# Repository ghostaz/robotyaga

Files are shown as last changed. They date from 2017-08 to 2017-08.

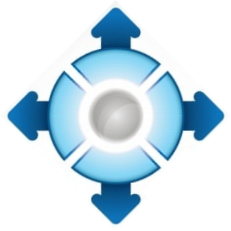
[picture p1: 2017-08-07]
Приложение/image/Стрелки.png

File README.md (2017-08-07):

# Роботяга
Платформа для сборки робота своими руками.
Вся информация по проекту доступна на сайте http://роботяга.рф

Коротко о платформе "Роботяга".
Платформа представляет собой гусеничное шасси с электронной платой. На плате содержится драйвер двигателя, аккумуляторы и микроконтроллер управляющий двигателями.
Взаимодействие с платформой осуществялется по проводному или беспроводному (Bluetooth) каналу через API. API позволяет управлять мощностью двигателей, получать заряд аккуумулятора. В дальнейшем планируется дополнить API и прошивку функционалом одометрии и работы платформы как ноды ROS.

Платформа предоставляет не только функции движения робота, но и функции питания. Втроенный аккумулятор имет защиту от перезаряда, переразряда, балансировку. На корпусы выведены 12 вольт непосредственно с аккумулыторов, 5 вольт через понижающий преобразователь с сильй тока до 2 ампер. Это позволяет вам подключить свое оборудование. Например, Raspberry Pi.

В даннмо репозитории выкладываются исходники схем. Использование схем бесплатно, исходники открыты по лицензией GPL v3. Прошивка микроконтроллера распрастраняется так же бесплатно, но исходники не предоставляются.

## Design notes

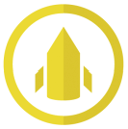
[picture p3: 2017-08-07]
Приложение/image/appico_hdpi.png

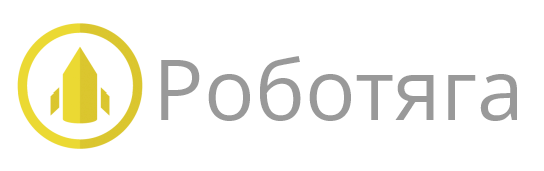
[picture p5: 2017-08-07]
Приложение/image/ЛогоМал.png

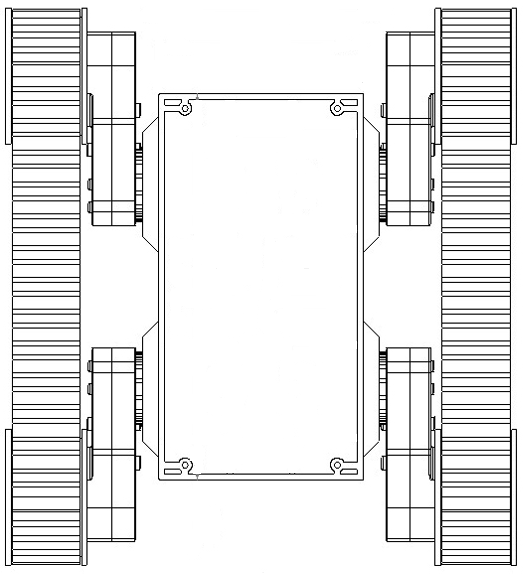
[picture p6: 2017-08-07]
Приложение/image/ВидСверху.png

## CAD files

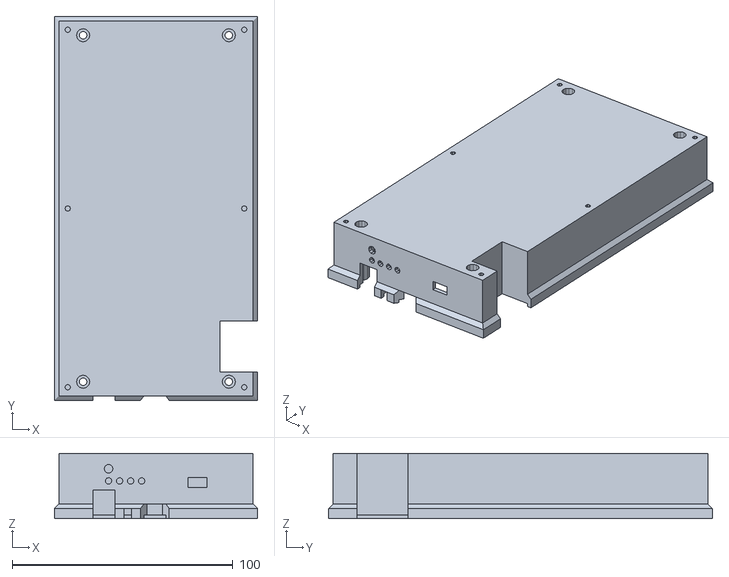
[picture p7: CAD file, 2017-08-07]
Корпус/Корпус_v1.4.stl
92.0 x 174.0 x 29.6

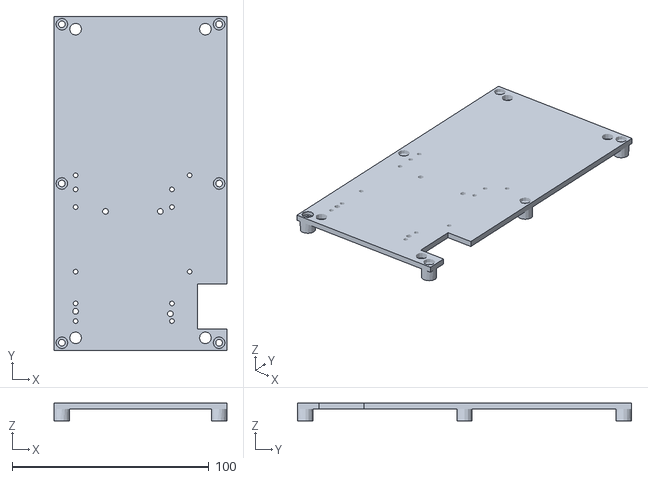
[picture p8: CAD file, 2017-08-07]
Корпус/Корпус_v1.4_Верх.stl
88.0 x 170.0 x 9.00

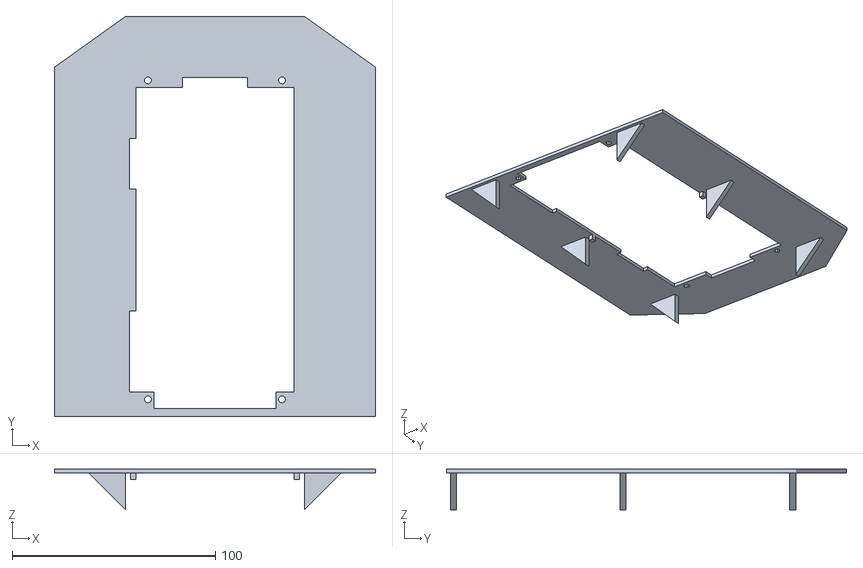
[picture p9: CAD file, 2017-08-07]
Корпус/Корпус_v1.4_Крыло.stl
158.0 x 197.0 x 20.0

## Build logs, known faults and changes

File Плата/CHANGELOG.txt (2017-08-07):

Версия 1.3 - Начата 26.03.2017
1 - Увеличено посадочное место под резистор 330Ом
2 - Разъем для индикатора заряда перенесен к выключаетлю
3 - Разъем питания Monster Shield изменени на разьем с 2мя контактами с шагом 2.54
4 - Разьемы питания на плате составлены таким образом что бы все провода были стандартными и подходили для любого разъема
5 - Отверстия для проброски проводов в корпус сделаны открытыми
6 - Знаки + и - для коннекторов моторов смещены, так что бы были видны после пайки коннектора
7 - Знаки + и - для держателя батарей смещены наружу, т.к. закрывались держателем
8 - Отверстия для крпления платы увеличены и перенесены на 0,5мм
9 - Увеличены отверстия для разъема DC3016
10 - Обозначения контактов выведен за границы, иначе были не видны
11 - Плата заряда батареи сдвинут внутрь корпуса
12 - Сдвинуты на пол миллиметра выключатель и разем питания что бы немешать корпусу.

Версия 1.4 - Начата 15.05.2017
1 - Добавлен регулятор напряжения на 5 вольт для питания Raspberry Pi
2 - Надпись Роботяга сделана на киррилице.

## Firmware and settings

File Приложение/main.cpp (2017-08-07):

#include <QGuiApplication>
#include <QQmlApplicationEngine>
#include <QQmlContext>
#include <QtQuick/QQuickView>

#include "bluetoothmanager.h"


int main(int argc, char *argv[])
{

    QCoreApplication::setAttribute(Qt::AA_EnableHighDpiScaling);
    QGuiApplication app(argc, argv);
    QQuickView view;

    BluetoothManager bluetoothManager;
    view.rootContext()->setContextProperty("bluetoothManager", QVariant::fromValue(&bluetoothManager));

    view.setSource(QUrl(QStringLiteral("qrc:/main.qml")));
    view.setResizeMode(QQuickView::SizeRootObjectToView);

    view.show();
    return app.exec();

}

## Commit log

2017-03-01 Добавил файл схемы платы
2017-03-03 Добавил открытую лицензию для проекта
2017-03-05 Добавил прошивку
2017-03-13 Добавил прошивку версии 0.1.0.13
2017-06-19 Rename Корпус_v1.3 - Верх.stl to Корпус_v1.3_Верх.stl
    [Корпус_v1.3_Верх.stl]
2017-07-22 Add files via upload
    Версия 1.5 - Начата 13.06.2017
    1 - Исправлено критически близкое положение минуса батареи и плюса модуля Bluetooth
2017-07-22 Версия 1.4 - Начата 21.07.2017 - Мелкие доработки
    Корпус - Версия 1.4 - Начата 21.07.2017
    1 - Крыло удленнено на 2 мм. Иначе ее размер ограничивался размером Rover5, а корпус сверху выстулпа на 2 мм
    2 - Модернизировано крпление датчика уровня заряда. Теперь установка проще.
    3 - Вырез под выключатель сделан шыре для удобства.
    4 - В крыле сделан вырез под контакты. Без выреза плата не устанавливается.
    6 - Вы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
    [Корпус_v1.4 - Верх.stl, Корпус_v1.4.stl, Корпус_v1.4_Крыло.stl]
2017-07-24 Версия: 0.1.0.14 - 24.07.2017 - Изменение полярности двигателей
    Версия: 0.1.0.14 - 24.07.2017
    Из за разводки проводов на плате версии 1.4 и 1.5 гусеницы крутятся в разные стороны. Технически это правильно, т.к. они расположены на разных сторонах робота.
    Но надо чтобы двигались вперед, потому поменял программно полярность на двигателях
2017-08-07 Тест приложения
2017-08-07 Тест папок
2017-08-07 Изменил способ хранения файлов. Теперь отдельно хранятся сборки и всегда есть папка текущей версии для ссылок с сайтов
    [Case_v1.1.stl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]
2017-08-07 Название платформы на кириллице.
2017-08-07 Переименовал папку чтобы было без пробела
    [PCB_1_5_copper_bottom.gbr, PCB_1_5_copper_top.gbr, PCB_1_5_outline.gbr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]
2017-08-07 Решил хранить только текущую версию.
    [PCB_1_5_copper_bottom.gbr, PCB_1_5_copper_top.gbr, PCB_1_5_outline.gbr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]
2017-08-07 Залил исполняемый файл мобильного приложения.
